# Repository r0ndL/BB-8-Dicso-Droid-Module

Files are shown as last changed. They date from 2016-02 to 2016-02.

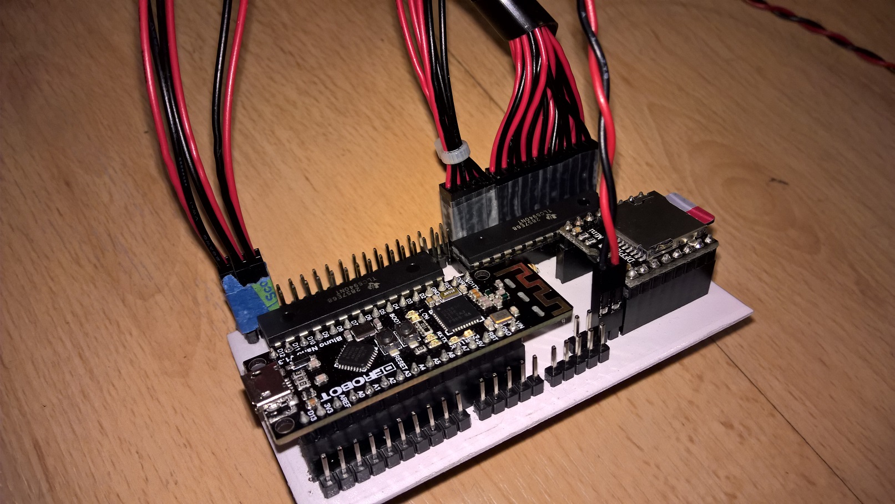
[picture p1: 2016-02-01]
Photos/WP_20160128_22_27_52_Pro_LI - Copy.jpg

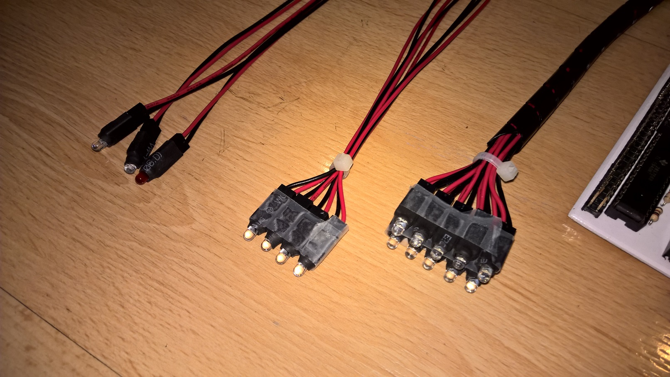
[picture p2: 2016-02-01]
Photos/WP_20160128_22_26_54_Pro_LI - Copy.jpg

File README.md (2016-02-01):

# BB-8-Dicso-Droid-Module
Released under CC4 SA NC BY Jim Yu

Disco-Droid 
Released under CC4 SA NC BY Jim Yu

#Introduction
The Disco Droid is an Arduino based module that will mainly provide Visual and Audio Effect for BB-8’s Dome. In order to create visual effects on the dome, more pins were needed that what an ordinary Arduino can provide, as such there was a need to create a module that has integrated output expander in order to accommodate the needs of the dome, and a few more extras for future upgrades. 
The Disco-Droid is capable working alone, or remotely controlled by another Bluetooth 4.0 LE device, it has a total of 32 12-bit PWM outputs, 7 spare analog pins from the Arduino, and 3 Digital I/O pins also from the Arduino, the Module has also integrated a MP3 Playback module that can drive a single 3W speaker. 

Most of all the different parts that was selected for this module has taken into account that many builders wish to make their domes as light as possible, in order to do so the Disco-Droid was design with the smallest off-the-shelf parts and modules in order to conserve on weight and size. The dimensions of the circuit board is just 2 x 3.5 x .7 inches, just slightly longer than your credit card. 

>Released under CC4 SA NC BY Jim Yu

#Roadmap
**V1.0.6 - Current Final Board Design for Version 1**
**Hardware Features**
- 32 PWM Output (Can handle Motors, LEDs, and Servos, etc..)
- 7 Analog Inputs (Can also be used for Digital Outputs)
- 3 Digital Outputs/Inputs
- 3W Speaker Output
- Bluetooth Ready
- Software Features
- Randomized Sound file playing
- 3 Pre-set Visualizer patterns 
- Small compact Code (using only 14% of the Arduino's memory, and 12% buffer memory)

**V1.1.6 - Same Board Design Utilizing Bluetooth remote connectivity**
**Hardware Features**
- Same as V1.0.6
- Software Features
- When left alone, it will follow V1.0.6 program functions
- Bluetooth Feature will be utilized to trigger the Dome light pattern changes, and sounds.

>In order to utilize V1.1.6 features a future Bluetooth Remote will be released to compliment the Disco-Droid Module.

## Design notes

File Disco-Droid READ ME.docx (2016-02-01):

# Disco-Droid

# Bluetooth Ready BB-8 Dome FX Module

### Roadmap

V1.0.6 - Current Final Board Design for Version 1
>Hardware Features
>>32 PWM Output (Can handle Motors, LEDs, and Servos, etc..)
>>7 Analog Inputs (Can also be used for Digital Outputs)
>>3 Digital Outputs/Inputs
>>3W Speaker Output
>>Bluetooth Ready

>Software Features
>>Randomized Sound file playing
>>3 Pre-set Visualizer patterns
>>Small compact Code (using only 14% of the Arduino's memory, and 12% buffer memory)
============================================================================

V1.1.6 - Same Board Design Utilizing Bluetooth remote connectivity
>Hardware Features
>>Same as V1.0.6

>Software Features
>>When left alone, it will follow V1.0.6 program functions
>>Bluetooth Feature will be utilized to trigger the Dome light pattern changes, and sounds.

*In order to utilize V1.1.6 features a future Bluetooth Remote will be released to compliment the Disco-Droid Module.

### Introduction

The Disco Droid is an Arduino based module that will mainly provide Visual and Audio Effect for BB-8’s Dome. In order to create visual effects on the dome, more pins were needed that what an ordinary Arduino can provide, as such there was a need to create a module that has integrated output expander in order to accommodate the needs of the dome, and a few more extras for future upgrades.

The Disco-Droid is capable working alone, or remotely controlled by another Bluetooth 4.0 LE device, it has a total of 32 12-bit PWM outputs, 7 spare analog pins from the Arduino, and 3 Digital I/O pins also from the Arduino, the Module has also integrated a MP3 Playback module that can drive a single 3W speaker.

Most of all the different parts that was selected for this module has taken into account that many builders wish to make their domes as light as possible, in order to do so the Disco-Droid was design with the smallest off-the-shelf parts and modules in order to conserve on weight and size. The dimensions of the circuit board is just 2 x 3.5 x .7 inches, just slightly longer than your credit card.

Released under CC4 SA NC BY Jim Yu

### Common trouble-shooting and assembly instructions

If you have gotten a completely assembled kit, all the components should have been soldered in, all you have to do is to attach the wires for the LEDs. Figure 1.0 will show you how your module should look like when you receive it.

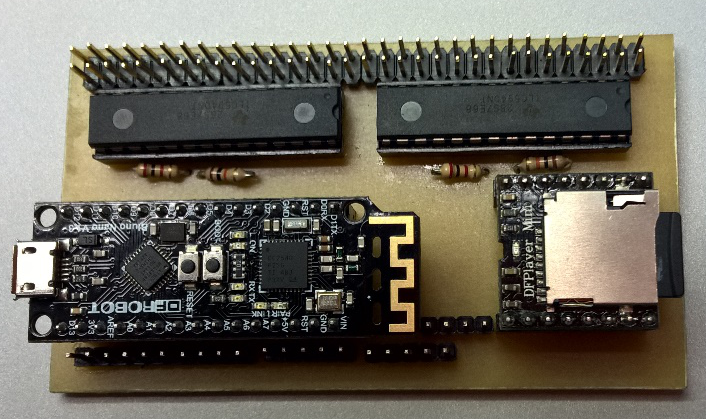
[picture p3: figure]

Figure 1.0 Disco-Droid Module with no attached Wires.

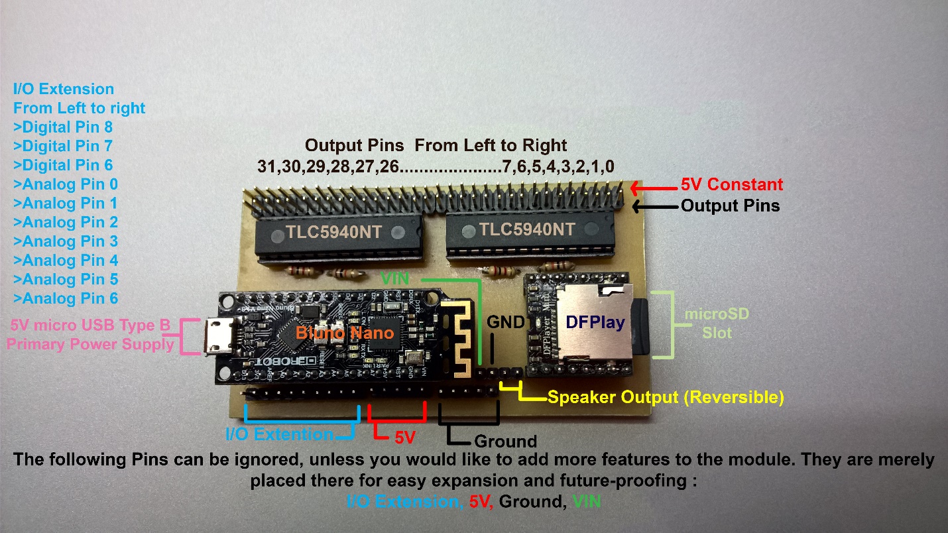
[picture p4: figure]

Figure 1.1 Completely labeled Disco-Droid Module.

For completely assembled kits, you will need to wire the LEDs and the speaker in. The LEDs in the package are bundled and labeled for quick and easy plugging.

When plugging the LEDs please be sure that the red wires are facing outside, and plugged into the 5V constant. The sequence in which you plug the LEDs are very important if you do not wish to modify the pre-loaded program. The proper LED wiring sequence is shown below.

Output Pins 0-4 → Front Top Logics
Output Pins 5-9 → Front Bottom Logics
Output Pins 10-13 → Side Logics
Output Pin 29 → Radar Eye LED
Output Pin 30 → Holoprojector LED
Output Pin 31 → PSI LED
Output Pins 28-24 → Optional 5 Radar Eye LED

The other set of wires that will need to be connected is for the speaker. Simply follow Figure1.1 to locate where the speaker output should be connected, orientation does not matter in this case.

All modules will have been tested to work before shipping, as such attaching the LED and speaker wires, and connecting the 5V power supply will immediately power up the module, should it somehow not power up or there are lose parts upon arrival, please message me and I will assist you to get the module working.

*Should there be lose parts upon arrival please immediately send me a photo and do not power it up yet, by design having lose components will not damage the circuit, but it is always better to be safe.

### Basic Program Modification

Disco-Droid is based on Arduino, an open-sourced platform used by many hackers and enthusiasts, it is quick and easy to understand and learn. In order to open the program of the Disco-Droid Module, you will need to download the Arduino IDE, the download link is below.

Arduino IDE Download Link (https://www.arduino.cc/en/Main/Software)

After installing the Arduino IDE, you will need to open the Libraries folder that I uploaded and copy the two folders inside into your Arduino Library, this adds the libraries needed by Arduino in order to properly program the Disco-Droid.

*The Arduino Library is typically found in C:\Program Files (x86)\Arduino\libraries

The program is written to be very easy to understand, I have placed comments on almost all the lines of the program to help you understand it. However, should you really just want to make modifications to the visualizer and nothing drastic it will only require you to change a few key words!

Figure 2.0

In order to change the visualizer sequence for the Logics lights, all you have to do is replace the Keywords that are highlighted in yellow. The suggested refresh rate for each sequence is boxed in blue, you can opt to follow the values given, or you may experiment with the values yourself.

*Refresh rate value is in milliseconds. Ex. Sweeper will sweep from 1 LED to another every 200 milliseconds, Randomizer will generate a new set of brightness values every 75 milliseconds.

For example, you want to change Front Logics 2 to have the Randomizer sequence, you may simply change the code, from Fader Fr_Logics_2(5, 9, 1); to Randomizer Fr_Logics_2(5, 9, 75);

Each MP3 module may give a slightly different output value, generally it will give almost the same values, however, if you are not satisfied with the reaction of the PSI LED to the speaker output of the Droid, you can also easily tweak a few values.

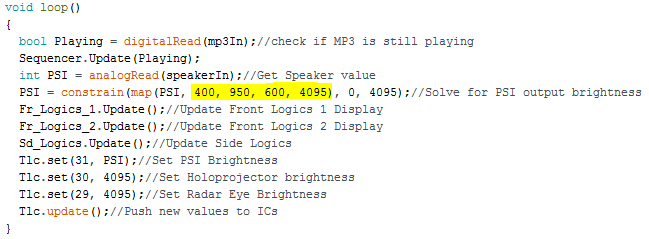
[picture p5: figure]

Figure 2.1

The Values highlighted in yellow are can be tweaked to your liking, it can make your droid more or less responsive depending you the values you enter.

The format is as follows map(PSI, fromLow, fromHigh, toLow, toHigh)

- fromLow is the anticipated lowest input value from the speaker
- fromHigh is the anticipated highest input value from the speaker
- toLow is the desired lowest LED output brightness
- toHigh is the desired highest LED output brightness

Once you have finished making your desired changes, simply plug the Bluno Nano into your computer, and upload your program.

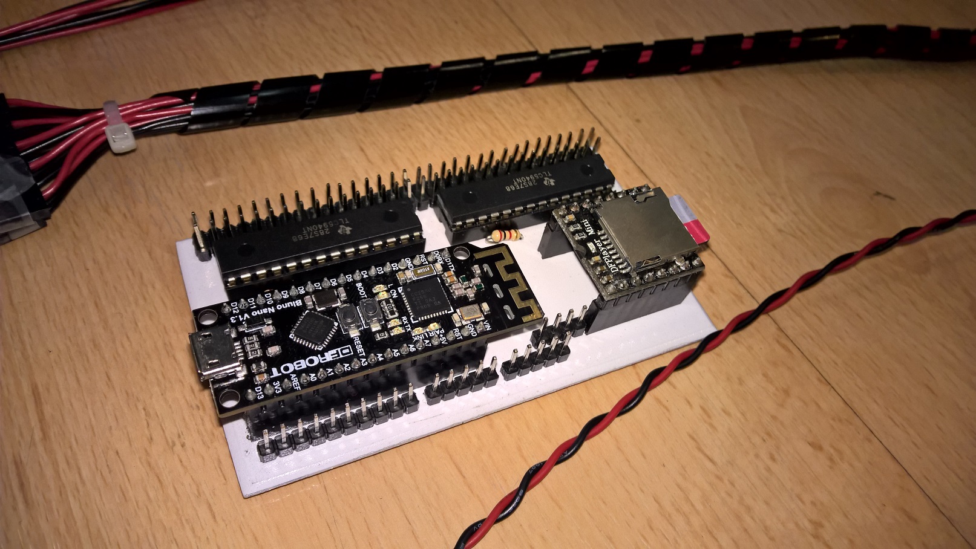
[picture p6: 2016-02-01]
Photos/WP_20160128_22_26_46_Pro_LI - Copy.jpg

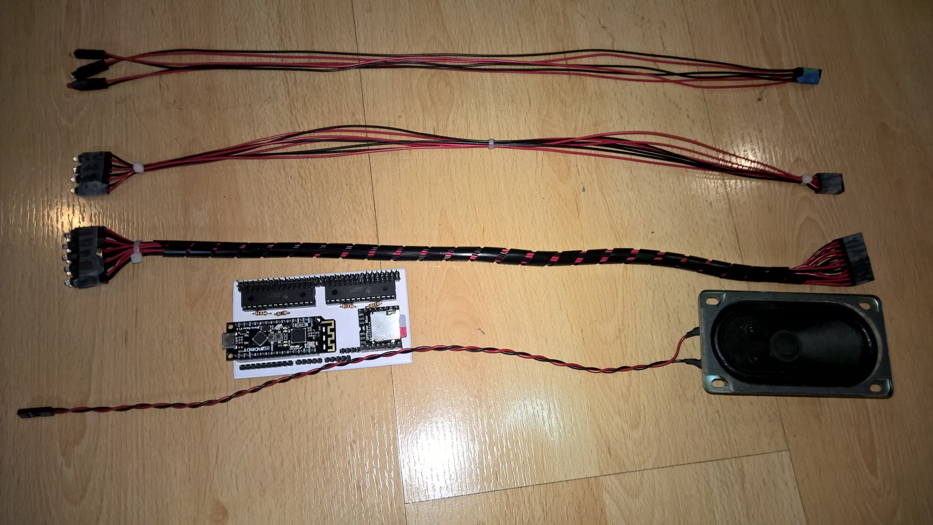
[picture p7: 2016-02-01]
Photos/WP_20160128_22_18_29_Rich_LI - Copy.jpg

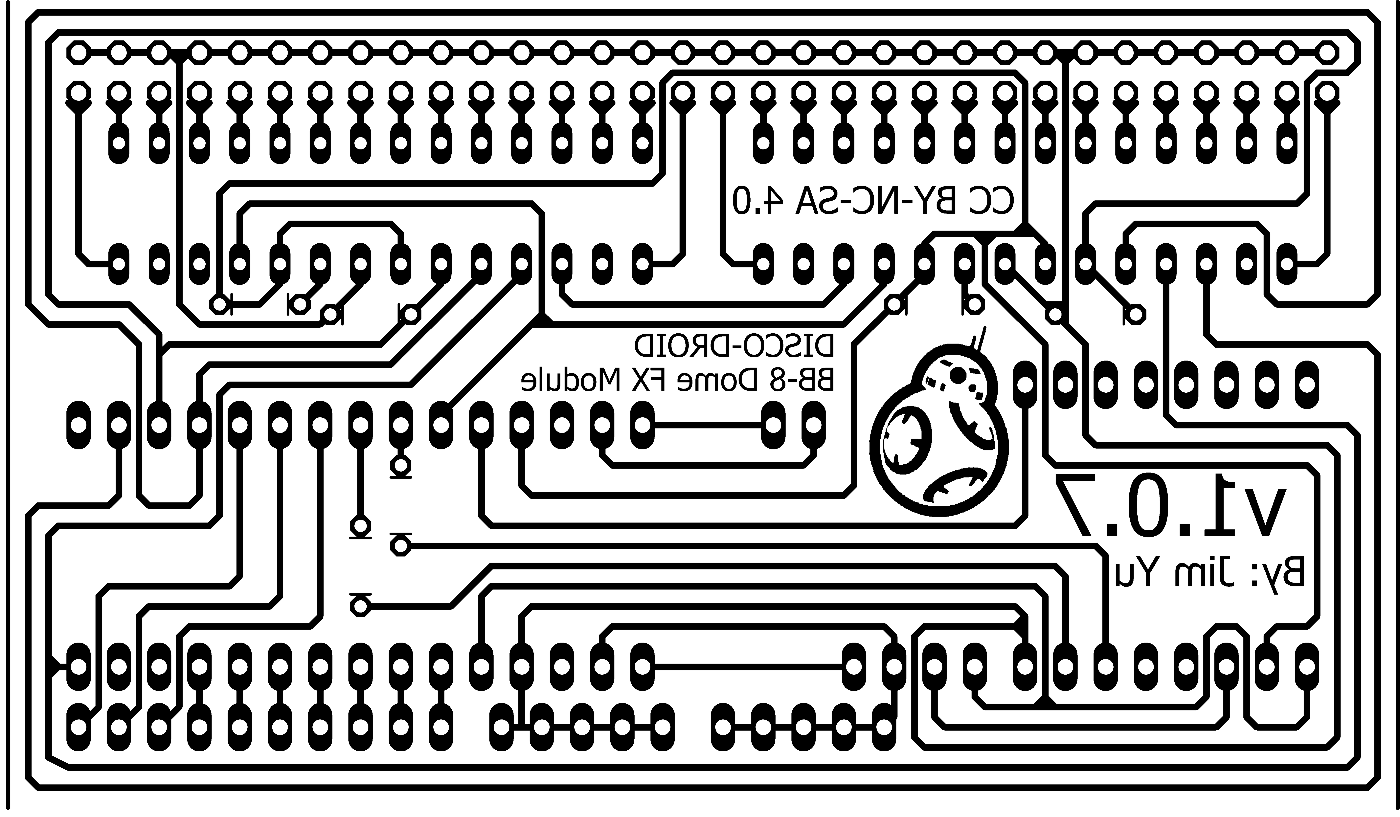
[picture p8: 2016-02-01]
BB-8 Dome FX Module/Dome FX.png

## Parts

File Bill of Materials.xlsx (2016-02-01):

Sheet: Limited Run 1
Disco-Droid : Bluetooth Ready BB-8 Dome Lights and Sounds Module |  |  |  |  | Running Total | 79.7958
Item | Quantity | PHP | USD | Total Price
Bluno nano | 1 | 1700 | 35.7 | 35.7 |  | Items Included in the Kit (~$200 + Shipping) [Club Approved]
DFPlay | 1 | 450 | 9.45 | 9.45 |  | Completed Disco-Droid Dome FX Module
TLC5940NT | 2 | 330 | 6.93 | 13.86 |  | Set of pre-wired LEDs
28-DIP Socket | 2 | 10 | 0.21 | 0.42 |  | Speaker
8W Speaker | 1 | 90 | 1.89 | 1.89 |  | MicroSD for BB-8 Sound Files
PCB | 1 | 250 | 5.25 | 5.25
5mm (Super Bright Red) | 1 | 4 | 0.084 | 0.084 |  | Items you will need to provide
3mm (Super Bright Blue) | 4 | 3 | 0.063 | 0.252 |  | Mobile Phone Powerbank
3mm (Super Bright White) | 10 | 3 | 0.063 | 0.63 |  | Micro USB type B connector (Andorid Phone Charger)
5mm White Super Bright | 1 | 4 | 0.084 | 0.084 |  | Optional Enclosure
5mm Blue Super Bright | 1 | 4 | 0.084 | 0.084
Ressistor 1k | 2 | 0.5 | 0.0105 | 0.021
Ressistor 2k | 2 | 0.5 | 0.0105 | 0.021
Ressistor 10k | 2 | 0.5 | 0.0105 | 0.021
2x8 Male Header Connector | 4 | 15 | 0.315 | 1.26
1x8 Femlae Header Connector | 4 | 13 | 0.273 | 1.092
Double 2 Pin Jumper Cable | 19 | 8 | 0.168 | 3.192
1x10 Male Header | 2 | 4 | 0.084 | 0.168
1x4 Male Header | 1 | 0.8 | 0.0168 | 0.0168
MicroSD Card 4GB | 1 | 300 | 6.3 | 6.3

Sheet: Run 2 Tentative Quotes
Disco-Droid : Bluetooth Ready BB-8 Dome Lights and Sounds Module |  |  |  |  | Running Total | 63.0378
Item | Quantity | PHP | USD | Total Price
Bluno nano | 1 | 1400 | 29.4 | 29.4 |  | Items Included in the Kit (~$200 + Shipping) [Club Approved]
DFPlay | 1 | 380 | 7.98 | 7.98 |  | Completed Disco-Droid Dome FX Module
TLC5940NT | 2 | 220 | 4.62 | 9.24 |  | Set of pre-wired LEDs
28-DIP Socket | 2 | 7 | 0.147 | 0.294 |  | Speaker
8W Speaker | 1 | 90 | 1.89 | 1.89 |  | MicroSD for BB-8 Sound Files
PCB | 1 | 100 | 2.1 | 2.1
3mm (Super Bright Red) | 1 | 4 | 0.084 | 0.084 |  | Items you will need to provide
3mm (Super Bright Blue) | 5 | 3 | 0.063 | 0.315 |  | Mobile Phone Powerbank
3mm (Super Bright White) | 11 | 3 | 0.063 | 0.693 |  | Micro USB type B connector (Andorid Phone Charger)
Ressistor 1k | 2 | 0.5 | 0.0105 | 0.021
Ressistor 2k | 2 | 0.5 | 0.0105 | 0.021
Ressistor 10k | 2 | 0.5 | 0.0105 | 0.021
2x8 Male Header Connector | 4 | 15 | 0.315 | 1.26
1x8 Femlae Header Connector | 4 | 13 | 0.273 | 1.092
Double 2 Pin Jumper Cable | 19 | 8 | 0.168 | 3.192
1x10 Male Header | 2 | 4 | 0.084 | 0.168
1x4 Male Header | 1 | 0.8 | 0.0168 | 0.0168
MicroSD Card 4GB | 1 | 250 | 5.25 | 5.25

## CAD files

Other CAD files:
BB-8 Dome FX Case/BB-8 Dome FX Case Bottom.CATPart
BB-8 Dome FX Case/BB-8 Dome FX Case Top.CATPart

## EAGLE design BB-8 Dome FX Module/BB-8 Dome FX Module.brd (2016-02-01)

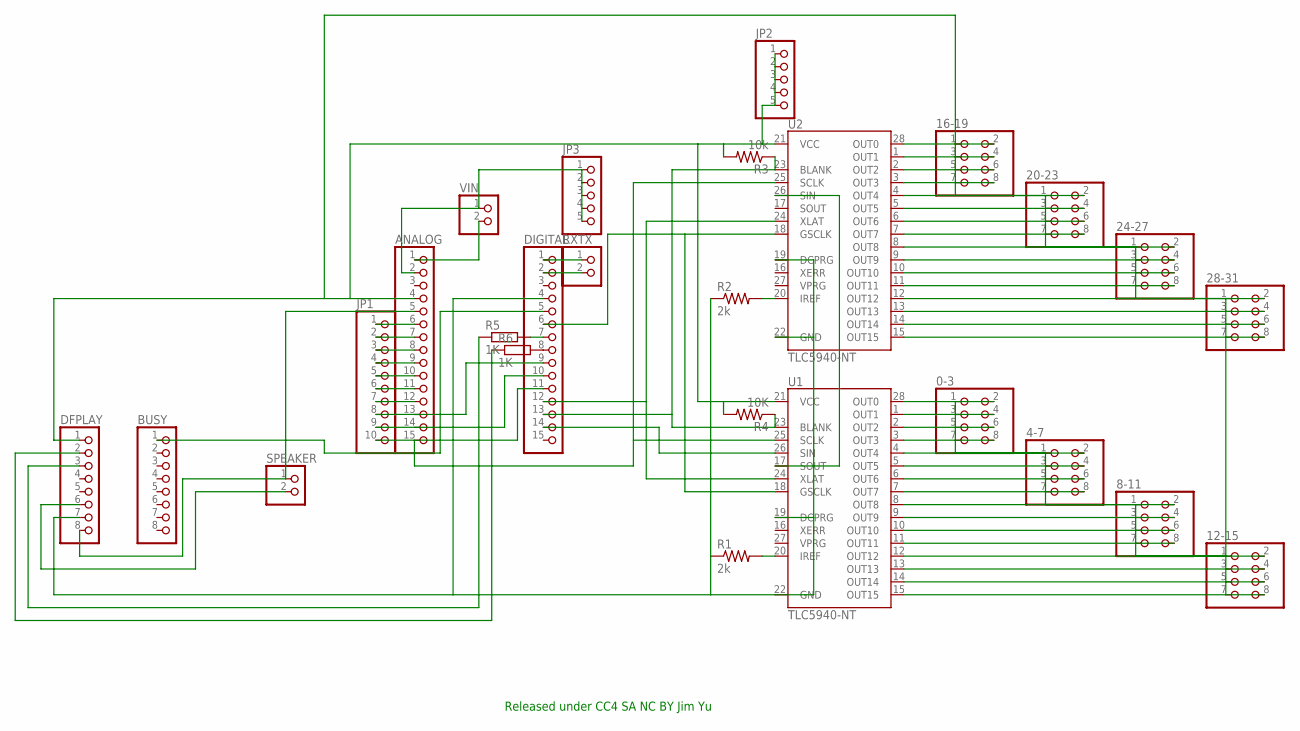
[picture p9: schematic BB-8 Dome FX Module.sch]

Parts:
0-3, 4-7, 8-11, 12-15, 16-19, 20-23, 24-27, 28-31: PINHD-2X4; 2X04
ANALOG: PINHD-1X15; 1X15
BUSY: PINHD-1X8; 1X08
DFPLAY: PINHD-1X8; 1X08
DIGITAL: PINHD-1X15; 1X15
JP1: PINHD-1X10; 1X10
JP2, JP3: PINHD-1X5; 1X05
R1, R2: 2k; 0204/5
R3: 10k; 0204/5
R4: 10K; 0204/5
R5, R6: 1K; 0204/5
RXTX: PINHD-1X2; 1X02
SPEAKER: PINHD-1X2; 1X02
U1, U2: TLC5940-NT; DIL28-3
VIN: PINHD-1X2; 1X02

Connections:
unnamed: DIGITAL.7, R5.2
unnamed: U1.17 (SOUT), U2.26 (SIN)
unnamed: DIGITAL.13, R3.1, R4.1, U1.23 (BLANK), U2.23 (BLANK)
unnamed: DIGITAL.12, U1.24 (XLAT), U2.24 (XLAT)
unnamed: DIGITAL.14, U1.26 (SIN)
unnamed: DIGITAL.6, U1.18 (GSCLK), U2.18 (GSCLK)
unnamed: ANALOG.15, U1.25 (SCLK), U2.25 (SCLK)
unnamed: DFPLAY.3, R5.1
unnamed: R2.2, U2.20 (IREF)
unnamed: R1.2, U1.20 (IREF)
unnamed: DFPLAY.2, R6.1
unnamed: DIGITAL.1, RXTX.1
unnamed: 16-19.4, U2.1 (OUT1)
unnamed: DIGITAL.2, RXTX.2
unnamed: 20-23.2, U2.4 (OUT4)
unnamed: 20-23.4, U2.5 (OUT5)
unnamed: 0-3.2, U1.28 (OUT0)
unnamed: 0-3.4, U1.1 (OUT1)
unnamed: 0-3.6, U1.2 (OUT2)
unnamed: 0-3.8, U1.3 (OUT3)
unnamed: 4-7.4, U1.5 (OUT5)
unnamed: 8-11.2, U1.8 (OUT8)
unnamed: 8-11.4, U1.9 (OUT9)
unnamed: 8-11.6, U1.10 (OUT10)
unnamed: 8-11.8, U1.11 (OUT11)
unnamed: 12-15.4, U1.13 (OUT13)
unnamed: 12-15.6, U1.14 (OUT14)
unnamed: 0-3.1, 0-3.3, 0-3.5, 0-3.7, 4-7.1, 4-7.3, 4-7.5, 4-7.7, 8-11.1, 8-11.3, 8-11.5, 8-11.7, 12-15.1, 12-15.3, 12-15.5, 12-15.7, 16-19.1, 16-19.3, 16-19.5, 16-19.7, 20-23.1, 20-23.3, 20-23.5, 20-23.7, 24-27.1, 24-27.3, 24-27.5, 24-27.7, 28-31.1, 28-31.3, 28-31.5, 28-31.7, ANALOG.4, DFPLAY.1, JP2.1, JP2.2, JP2.3, JP2.4, JP2.5, R3.2, R4.2, U1.21 (VCC), U2.21 (VCC)
unnamed: 12-15.8, U1.15 (OUT15)
unnamed: BUSY.1, DIGITAL.5
unnamed: ANALOG.5, DFPLAY.8, SPEAKER.1
unnamed: DFPLAY.6, SPEAKER.2
unnamed: DFPLAY.7, DIGITAL.4, R1.1, R2.1, U1.19 (DCPRG), U1.22 (GND), U2.19 (DCPRG), U2.22 (GND)
unnamed: DIGITAL.8, R6.2
unnamed: ANALOG.1, VIN.2
unnamed: ANALOG.2, JP3.1, JP3.2, JP3.3, JP3.4, JP3.5, VIN.1
unnamed: ANALOG.6, JP1.1
unnamed: ANALOG.7, JP1.2
unnamed: ANALOG.8, JP1.3
unnamed: ANALOG.9, JP1.4
unnamed: ANALOG.10, JP1.5
unnamed: ANALOG.11, JP1.6
unnamed: ANALOG.12, JP1.7
unnamed: DIGITAL.9, JP1.8
unnamed: DIGITAL.10, JP1.9
unnamed: DIGITAL.11, JP1.10
unnamed: 28-31.8, U2.15 (OUT15)
unnamed: 28-31.6, U2.14 (OUT14)
unnamed: 28-31.4, U2.13 (OUT13)
unnamed: 28-31.2, U2.12 (OUT12)
unnamed: 24-27.8, U2.11 (OUT11)
unnamed: 24-27.6, U2.10 (OUT10)
unnamed: 24-27.4, U2.9 (OUT9)
unnamed: 24-27.2, U2.8 (OUT8)
unnamed: 20-23.8, U2.7 (OUT7)
unnamed: 20-23.6, U2.6 (OUT6)
unnamed: 16-19.8, U2.3 (OUT3)
unnamed: 16-19.6, U2.2 (OUT2)
unnamed: 16-19.2, U2.28 (OUT0)
unnamed: 12-15.2, U1.12 (OUT12)
unnamed: 4-7.8, U1.7 (OUT7)
unnamed: 4-7.6, U1.6 (OUT6)
unnamed: 4-7.2, U1.4 (OUT4)

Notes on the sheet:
Released under CC4 SA NC BY Jim Yu

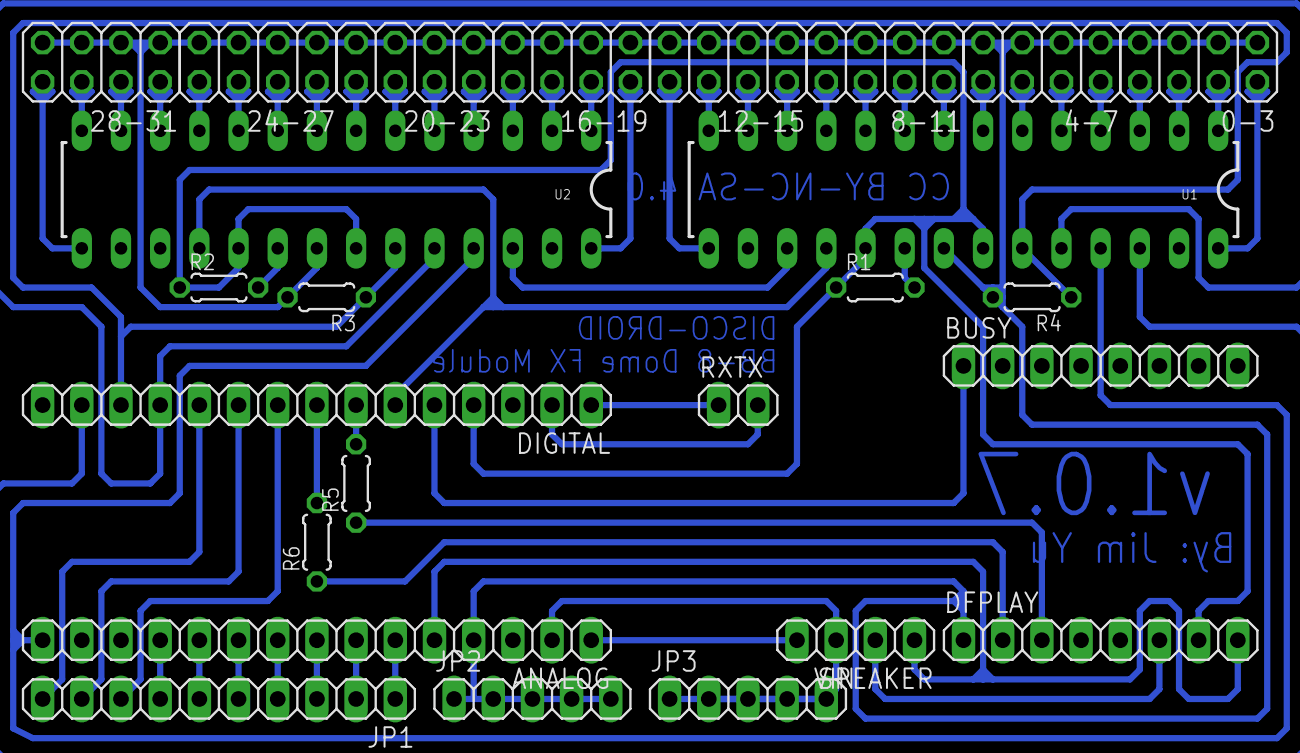
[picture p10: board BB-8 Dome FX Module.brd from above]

Board: 2 copper layers, 26 parts (0 on the bottom side), 63 nets.

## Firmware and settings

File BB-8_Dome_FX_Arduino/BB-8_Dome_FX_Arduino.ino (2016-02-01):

//Released under CC4 SA NC BY Jim Yu
//Libraries
#include <Tlc5940.h>
#include <SoftwareSerial.h>
#include <DFPlayer_Mini_Mp3.h>

//Pin Definitions
SoftwareSerial Sound(4, 5); // RX, TX
const int speakerIn = 7;
const int mp3In = 2;

//Global Variables
int volumeOut = 30;

class Sweeper///////////////////////////////////////////START SWEEPER CLASS///////////////////////////////////////////////////
{
    // Class Local Variables
    int first;          // channel of the first LED in the array
    int last;           // channel of the last LED in the array
    long interval;      // milliseconds of on-time

    // These maintain the current state
    int dir;                    // for tracking sweep direction
    int current;                // for tracking LED switching
    unsigned long lastMillis;   // will store last time LED was updated

  public:
    Sweeper(int firstLED, int lastLED, long intervalTime)//Constructor
    {
      first = firstLED;
      last = lastLED;
      interval = intervalTime;
      dir = 1;
      current = firstLED;
      lastMillis = 0;
    }

    void Update()//Sweeper Update Function
    {
      unsigned long nowMillis = millis();//get current time
      if (nowMillis >= (lastMillis + interval))//Check if it is time to update
      {
        lastMillis = nowMillis; //Save new time
        for (int channel = first; channel <= last; channel ++)
        {
          Tlc.set(channel, 0);
        }
        if (current <= last) //If current LED is not beyond the last
        {
          if (current == first) //and If currrent LED is the first
          {
            dir = 1; //Set direction to forward
          }
          else //If Current LED is not the first LED and not the last LED
          {
            //Tlc.set(current - 1, 1000); //Set the LED before to 25% brightness
          }
          Tlc.set(current, 4095); //Set current LED to maximum brightness
          if (current == last) //If current LED is the last
          {
            dir = -1; //Set direction to reverse
          }
          else //If current LED is not the last
          {
            //Tlc.set(current + 1, 1000); //Set the next LED to 25% brightness
          }
          current += dir;
        }
      }
    }
};//////////////////////////////////////////////////////END SWEEPER CLASS///////////////////////////////////////////////////
class Fader/////////////////////////////////////////////START FADER CLASS///////////////////////////////////////////////////
{
    // Class Local Variables
    int first;          // channel of the first LED in the array
    int last;           // channel of the last LED in the array
    long interval;      // milliseconds of on-time

    // These maintain the current state
    int current;                // for tracking LED updating
    int dimmer;                 // for tracking brightness
    int dim;
    unsigned long lastMillis;   // will store last time LED was updated

    // Constructor - creates a Fader
    // and initializes the member variables and state
  public:
    Fader(int firstLED, int lastLED, long intervalTime)//Constructor
    {
      first = firstLED;
      last = lastLED;
      interval = intervalTime;
      lastMillis = 0;
      dimmer = 1;
      dim = 1;
    }

    void Update()//Fader Update Function
    {
      unsigned long nowMillis = millis();//get current time
      if (nowMillis >= (lastMillis + interval))//Check if it is time to update
      {
        lastMillis = nowMillis;//Save new time
        for (int channel = first; channel <= last; channel++)
        {
          Tlc.set(channel, 0);
        }
        current = first;
        dimmer = constrain(dimmer, 0, 4095);//ensure brightness is between 0-4095
        while (current <= last)
        {
          Tlc.set(current, dimmer);
          current++;
        }
        dimmer = dimmer + dim;
        if (dimmer < 1)
        {
          dim = 1;
        }
        if (dimmer > 2000)
        {
          dim = -1;
        }
      }
    }
};//////////////////////////////////////////////////////END FADER CLASS///////////////////////////////////////////////////
class Randomizer////////////////////////////////////START RANDOMIZER CLASS////////////////////////////////////////////////
{
    // Class Local Variables
    int first;          // channel of the first LED in the array
    int last;           // channel of the last LED in the array
    long interval;      // milliseconds of on-time

    // These maintain the current state
    int current;                // for tracking LED updating
    int dimmer;                 // for tracking brightness
    unsigned long lastMillis;   // will store last time LED was updated

    // Constructor - creates a Randomizer
    // and initializes the member variables and state
  public:
    Randomizer(int firstLED, int lastLED, long intervalTime)//Constructor
    {
      first = firstLED;
      last = lastLED;
      interval = intervalTime;
      lastMillis = 0;
      dimmer = 0;
    }

    void Update()//Randomizer Update Function
    {
      unsigned long nowMillis = millis();//get current time
      if (nowMillis >= (lastMillis + interval))//Check if it is time to update
      {
        lastMillis = nowMillis;//Save new time
        current = first;
        //constrain(dimmer, 0, 4095);//ensure brightness is between 0-4095
        while (current <= last)
        {
          dimmer = random(0, 4095);
          Tlc.set(current, dimmer);
          current++;
        }
      }
    }
};//////////////////////////////////////////////////////END RANDOMIZER CLASS///////////////////////////////////////////////////
class Wave////////////////////////////////////////////START WAVE CLASS///////////////////////////////////////////////////
{
    // Class Local Variables
    int first;          // channel of the first LED in the array
    int last;           // channel of the last LED in the array
    long interval;      // milliseconds of on-time

    // These maintain the current state
    int current;                // for tracking LED updating
    int dimmer;                 // for tracking brightness
    unsigned long lastMillis;   // will store last time LED was updated

    // Constructor - creates a Flasher
    // and initializes the member variables and state
  public:
    Wave(int firstLED, int lastLED, long intervalTime)//Constructor
    {
      first = firstLED;
      last = lastLED;
      interval = intervalTime;
      lastMillis = 0;
      dimmer = 0;
    }

    void Update()//Wave Update Function
    {
      unsigned long nowMillis = millis();//get current time
      if (nowMillis >= (lastMillis + interval))//Check if it is time to update
      {
        for (int channel = first; channel <= last; channel ++)
        {
          Tlc.set(channel, 0);
        }
        current = first;
        dimmer = constrain(dimmer, 0, 4095);//ensure brightness is between 0-4095
        while (current <= last)
        {
          dimmer = 100 + (sin(millis() / 400.00) * 80);
          Tlc.set(current, dimmer);
          current++;
        }
      }
    }
};//////////////////////////////////////////////////////END WAVE CLASS///////////////////////////////////////////////////
class MP3Sequencer/////////////////////////////////START MP3Sequencer CLASS//////////////////////////////////////////////
{
    bool Play;
    long maxInterval;

    // These maintain the current state
    unsigned long lastMillis;   // will store last time LED was updated

    // Constructor - creates a Sequencer
    // and initializes the member variables and state
  public:
    MP3Sequencer(long intervalTime)//Constructor
    {
      maxInterval = intervalTime;
      lastMillis = 0;
    }

    void Update(bool isPlaying)//MP3Randomizer Update Function
    {
      unsigned long nowMillis = millis();//get current time
      Play = isPlaying;
      if (Play == HIGH) //Not Playing
      {
        int interval = random(1000,maxInterval);
        if (nowMillis >= (lastMillis + interval))//Check if it is time to update
        {
          mp3_next();//Play Next track
        }
      }
      else//Playing
      {
        lastMillis = millis();
      }

    }
};/////////////////////////////////////////////////////END MP3SEQUENCER CLASS////////////////////////////////////////////////






Sweeper Fr_Logics_1(0, 4, 200);
Fader Fr_Logics_2(5, 9, 0);
Randomizer Sd_Logics(10, 13, 75);
MP3Sequencer Sequencer(30000);

void setup()
{
  Tlc.init();//Initialize TLC ICs
  //Serial.begin (9600);
  Sound.begin (9600);//MP3 Baud Rate
  mp3_set_serial (Sound);//set softwareSerial for DFPlayer-mini mp3 module
  mp3_set_volume (volumeOut);//set volume
  pinMode(speakerIn, INPUT); //Connected to Speaker
  pinMode(mp3In, INPUT); //Connected to MP3 State
}

void loop()
{
  bool Playing = digitalRead(mp3In);//check if MP3 is still playing
  Sequencer.Update(Playing);
  int PSI = analogRead(speakerIn);//Get Speaker value
  PSI = constrain(map(PSI, 400, 950, 300, 4095), 0, 4095);//Solve for PSI output brightness
  Fr_Logics_1.Update();//Update Front Logics 1 Display
  Sd_Logics.Update();//Update Side Logics
  Fr_Logics_2.Update();//Update Front Logics 2 Display
  Tlc.set(31, PSI);//Set PSI Brightness
  Tlc.set(30, 4095);//Set Holoprojector brightness
  Tlc.set(29, 4095);//Set Radar Eye Brightness
  Tlc.update();//Push new values to ICs
}

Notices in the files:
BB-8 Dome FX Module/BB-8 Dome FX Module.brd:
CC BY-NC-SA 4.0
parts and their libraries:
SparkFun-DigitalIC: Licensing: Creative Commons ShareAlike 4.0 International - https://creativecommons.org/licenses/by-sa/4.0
